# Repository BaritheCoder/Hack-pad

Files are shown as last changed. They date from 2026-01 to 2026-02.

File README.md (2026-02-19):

# Hack-pad

My Hack-pad project repository.

([](https://github.com/BaritheCoder/Hack-pad/blob/main/V1/Images/Screenshot%202026-01-24%20123521.png?raw=true))

---

## Design Overview

| Case | PCB | Schematic |
|---|-----|---|
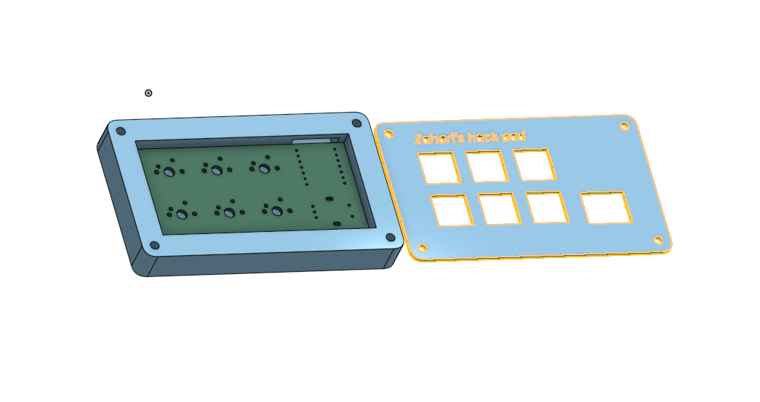
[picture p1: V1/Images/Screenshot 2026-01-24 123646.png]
Case
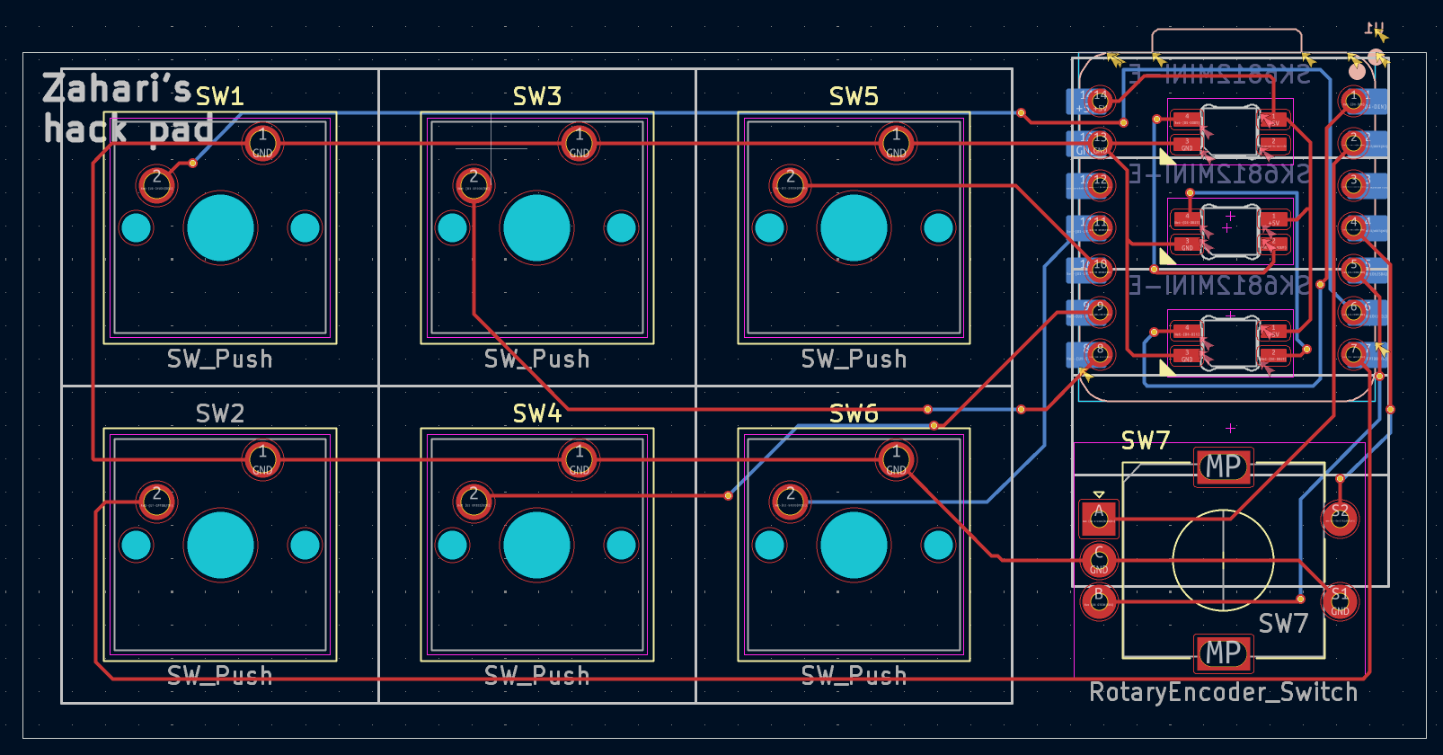
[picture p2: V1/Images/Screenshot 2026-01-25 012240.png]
PCB
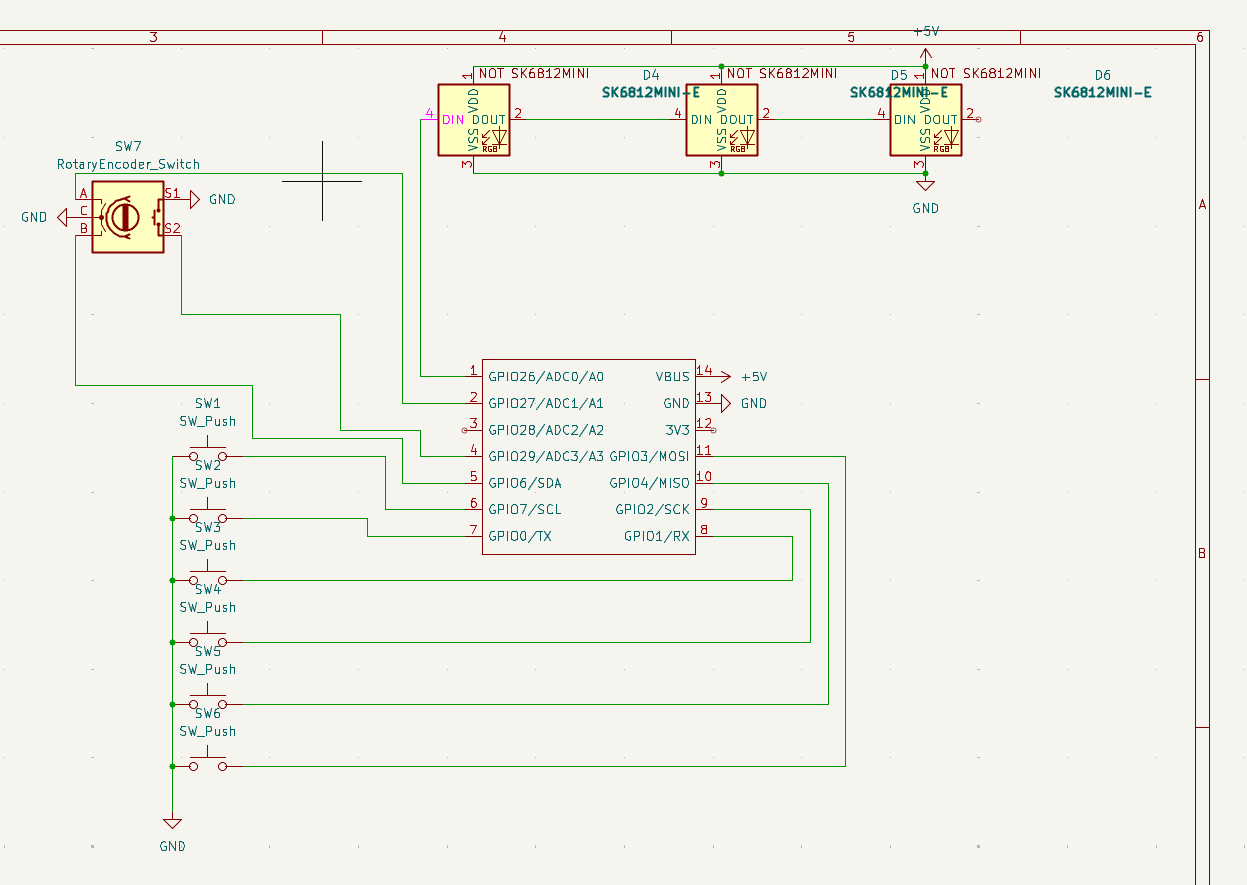
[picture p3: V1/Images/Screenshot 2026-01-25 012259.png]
Schematic
|  |  |  |

---

## Challenges

This was my first time using a PCB design program, but I really enjoyed the process and I’m looking forward to my next project that requires custom PCBs.

Although I have used CAD programs before, this project helped me learn many new things about both **PCB design** and **3D modeling**.

---

## Specifications

### Bill of Materials (BOM)

- **6×** Cherry MX switches  
- **3×** SK6812 MINI LEDs  
- **1×** XIAO RP2040  
- **1×** Rotary Encoder (Alps EC11E, vertical, with switch)  
- **6×** Blank DSA keycaps  
- **4×** M3×16 bolts  
- **4×** M3 heat-set inserts  

### Other Files & Tools
- KMK firmware  
- `Top Case.stl`  
- `Bottom Case.stl`  

---

## V2 Changes
- Changed LED position  
- Fixed schematic routing issue

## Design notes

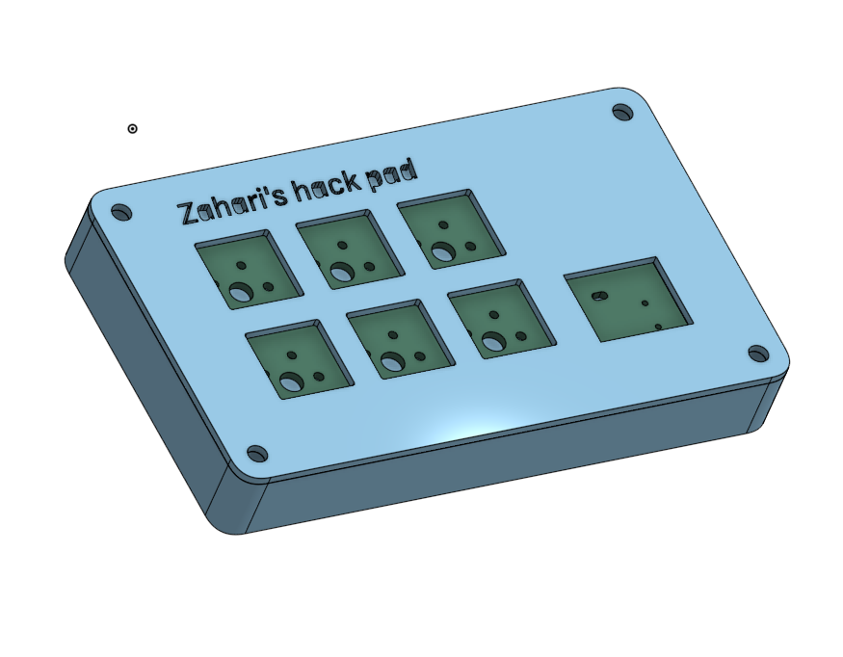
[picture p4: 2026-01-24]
V1/Images/Screenshot 2026-01-24 123521.png

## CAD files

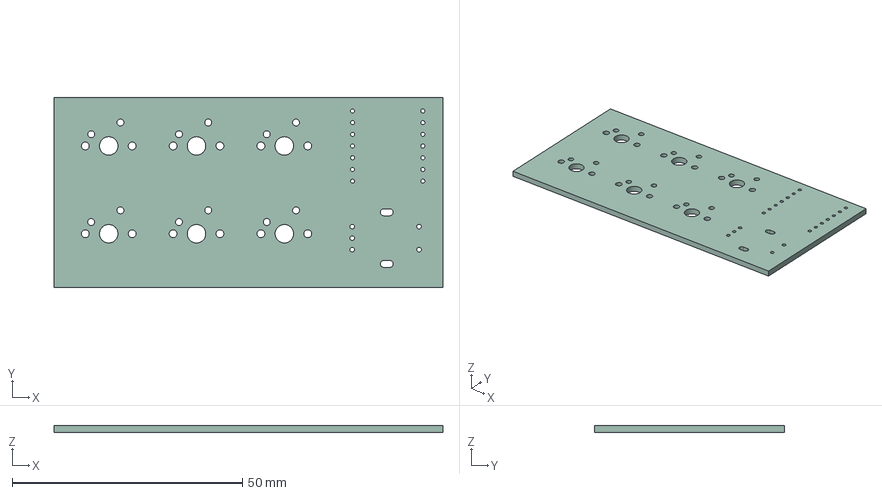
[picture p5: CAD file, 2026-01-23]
V1/CAD/Assembly 1 - Macro Pad_PCB.step
84.4 x 41.2 x 1.51 mm

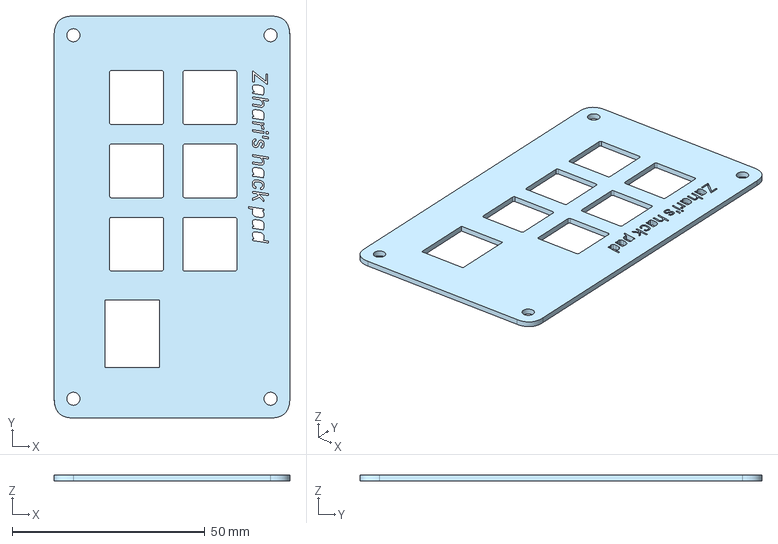
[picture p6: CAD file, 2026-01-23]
V1/CAD/Assembly 1 - Part 1.step
61.2 x 104.4 x 1.50 mm

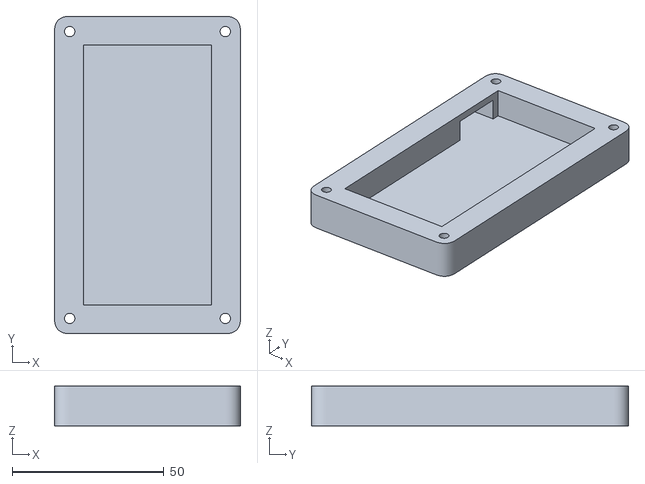
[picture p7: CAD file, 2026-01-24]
V1/Production/Bottom plate.stl
61.2 x 104.4 x 13.0

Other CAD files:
V1/CAD/Plate.stl
V1/Production/Top plate.stl
V1/CAD/Assembly 1 - Part 1 (1).step

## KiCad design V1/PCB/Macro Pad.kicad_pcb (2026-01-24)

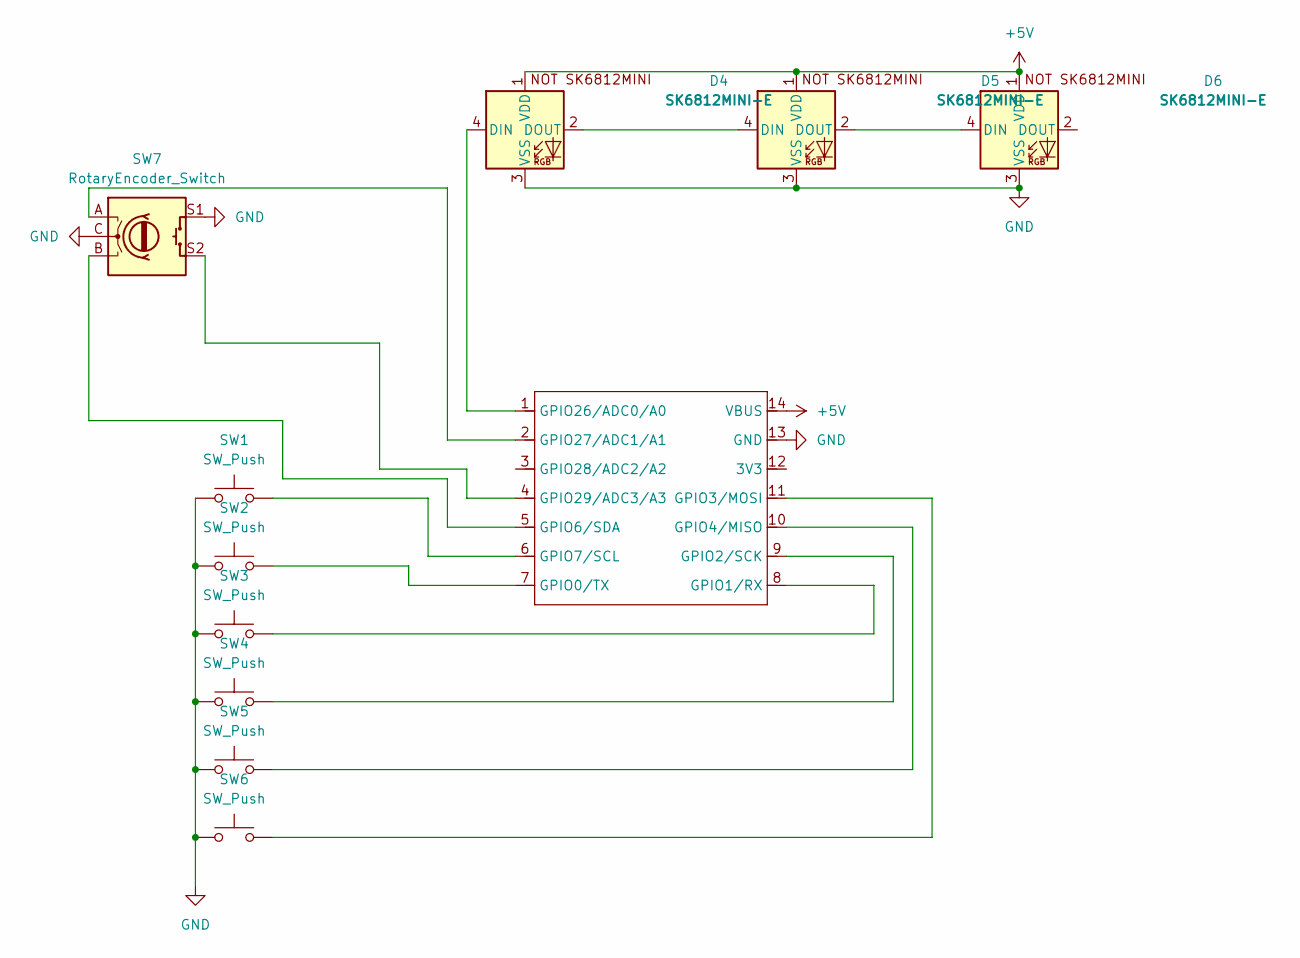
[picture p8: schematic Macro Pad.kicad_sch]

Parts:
D4, D5, D6: SK6812MINI-E; MX_SK6812MINI-E_REV
SW1, SW2, SW3, SW4, SW5, SW6: SW_Push; SW_Cherry_MX_1.00u_PCB
SW7: RotaryEncoder_Switch; RotaryEncoder_Alps_EC11E-Switch_Vertical_H20mm
U1: XIAO-RP2040-DIP

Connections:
+5V: D4.1 (VDD), D5.1 (VDD), D6.1 (VDD), U1.14 (VBUS)
GND: D4.3 (VSS), D5.3 (VSS), D6.3 (VSS), SW1.1, SW2.1, SW3.1, SW4.1, SW5.1, SW6.1, SW7.C, SW7.S1, U1.13 (GND)
unnamed: D4.4 (DIN), U1.1 (GPIO26/ADC0/A0)
unnamed: D4.2 (DOUT), D5.4 (DIN)
unnamed: D5.2 (DOUT), D6.4 (DIN)
unnamed: SW2.2, U1.7 (GPIO0/TX)
unnamed: SW3.2, U1.8 (GPIO1/RX)
unnamed: SW4.2, U1.9 (GPIO2/SCK)
unnamed: SW6.2, U1.11 (GPIO3/MOSI)
unnamed: SW5.2, U1.10 (GPIO4/MISO)
unnamed: SW7.B, U1.5 (GPIO6/SDA)
unnamed: SW1.2, U1.6 (GPIO7/SCL)
unnamed: SW7.A, U1.2 (GPIO27/ADC1/A1)
unnamed: SW7.S2, U1.4 (GPIO29/ADC3/A3)

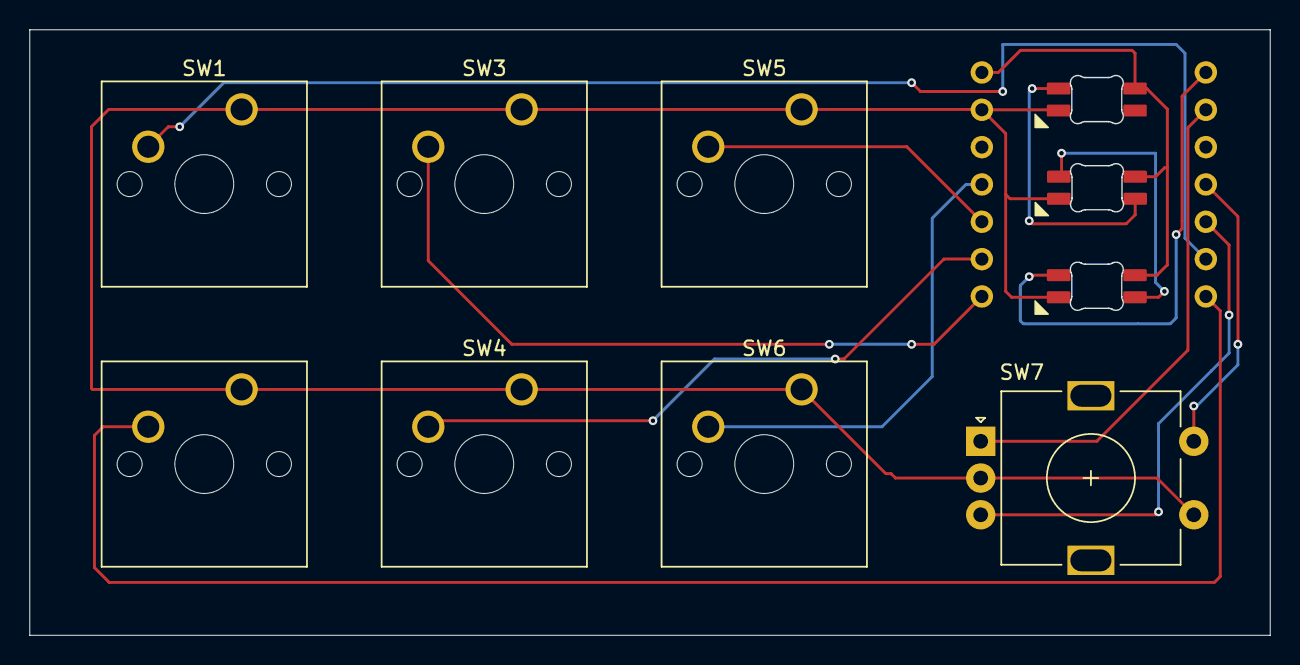
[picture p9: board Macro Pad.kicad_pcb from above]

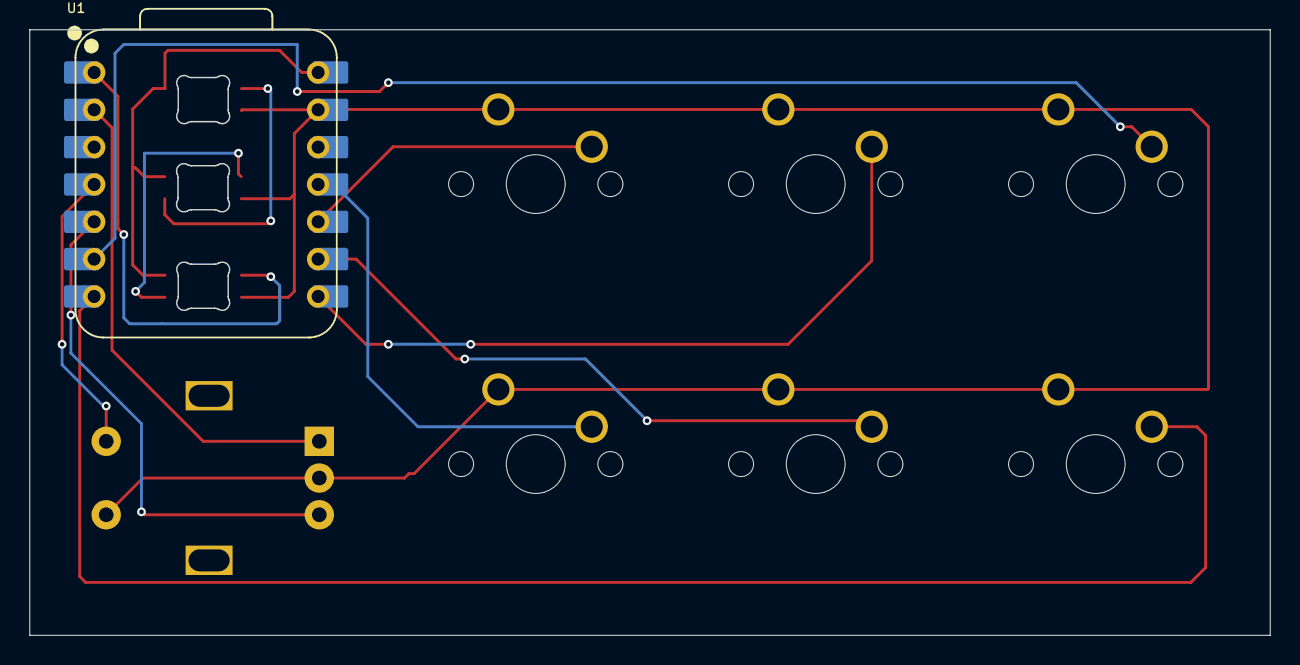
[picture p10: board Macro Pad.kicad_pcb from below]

Board: 2 copper layers, 84.4 x 41.2 mm, 11 parts (4 on the bottom side), 14 nets.

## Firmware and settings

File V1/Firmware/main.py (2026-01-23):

import board

from kmk.kmk_keyboard import KMKKeyboard
from kmk.scanners.keypad import KeysScanner
from kmk.keys import KC

from kmk.modules.encoder import EncoderHandler
from kmk.modules.layers import Layers as _Layers
from kmk.extensions.rgb import RGB


keyboard = KMKKeyboard()

# -----------------------
# 6 individual switches
# -----------------------
PINS = (
    board.GP7,  # switch 1
    board.GP0,  # switch 2
    board.GP1,  # switch 3
    board.GP2,  # switch 4
    board.GP4,  # switch 5
    board.GP3,  # switch 6
)

keyboard.matrix = KeysScanner(
    pins=PINS,
    value_when_pressed=False,
)

# -----------------------
# RGB (3x SK6812mini) on GP26
# -----------------------
# If your SK6812mini are RGBW, you may need rgb_order=(1,0,2,3) like some examples.
# If they are RGB only, leave rgb_order out.
rgb = RGB(
    pixel_pin=board.GP26,
    num_pixels=3,
    # rgb_order=(1, 0, 2, 3),  # <- uncomment if your LEDs are RGBW
)
keyboard.extensions.append(rgb)

# Make RGB show the current "mode" (top layer) by changing color
class Layers(_Layers):
    last_top_layer = 0
    # 3 distinct hues for 3 modes (0/1/2)
    hues = (4, 20, 69)

    def after_hid_send(self, keyboard):
        top = keyboard.active_layers[0]
        if top != self.last_top_layer:
            self.last_top_layer = top
            rgb.set_hsv_fill(self.hues[top], 255, 255)

layers = Layers()
keyboard.modules.append(layers)

# -----------------------
# Rotary encoder
# A=GP27, B=GP6, Button=GP29
# -----------------------
encoder_handler = EncoderHandler()
keyboard.modules.append(encoder_handler)

encoder_handler.pins = (
    (board.GP27, board.GP6, board.GP29, False),  # (A, B, button, inverted?)
)

# Per-layer encoder actions: (left, right, press)
# Press cycles modes: 0->1, 1->2, 2->0
encoder_handler.map = [
    # Mode 0
    ((KC.VOLD, KC.VOLU, KC.DF(1)),),
    # Mode 1
    ((KC.PGDN, KC.PGUP, KC.DF(2)),),
    # Mode 2
    ((KC.LEFT, KC.RIGHT, KC.DF(0)),),
]

# -----------------------
# Keymaps for the 6 switches (3 modes/layers)
# -----------------------
keyboard.keymap = [
    # Mode 0 (Layer 0) - example
    [
        KC.A, KC.B, KC.C, KC.D, KC.E, KC.F
    ],

    # Mode 1 (Layer 1) - example
    [
        KC.MPLY, KC.MPRV, KC.MNXT, KC.MUTE, KC.VOLD, KC.VOLU
    ],

    # Mode 2 (Layer 2) - example
    [
        KC.ESC, KC.TAB, KC.ENTER, KC.BSPC, KC.DEL, KC.SPC
    ],
]

if __name__ == "__main__":
    keyboard.go()

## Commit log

2026-01-23 Update files
    [Assembly 1 - Macro Pad_PCB.step, Assembly 1 - Part 1 (1).step, Assembly 1 - Part 1.step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]
2026-01-24 Update README with project challenges and specifications
    Added project challenges and specifications including BOM.
2026-01-24 Update PCB image link in README
2026-01-24 Update schematic image link in README
    Fixed image link for schematic in README.
2026-01-24 Fix image link for schematic in README
